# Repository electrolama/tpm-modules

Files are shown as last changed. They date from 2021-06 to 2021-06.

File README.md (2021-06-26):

# tpm-modules

KiCAD (v5.99) designs for Infineon SLB9665 and SLB9670 based TPM modules.

There are two interfaces: SPI (SLB9670) and LPC (SLB9665). Pinouts for the modules vary a lot ([manufacturer specific?](https://superuser.com/a/1537838)) but given how simple the boards are adding new ones should be fairly straightforward. 

Modules in this repo:

**tpm-module-12pin-spi**

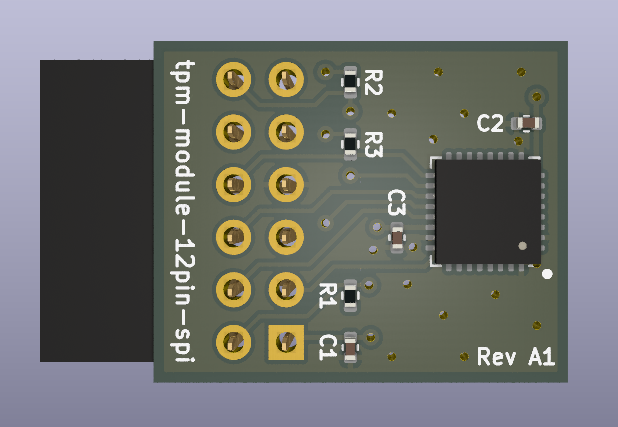
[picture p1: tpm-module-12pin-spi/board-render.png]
tpm-module-12pin-spi


`Status:` Untested, parts ordered for prototypes

**tpm-module-14pin-lpc**

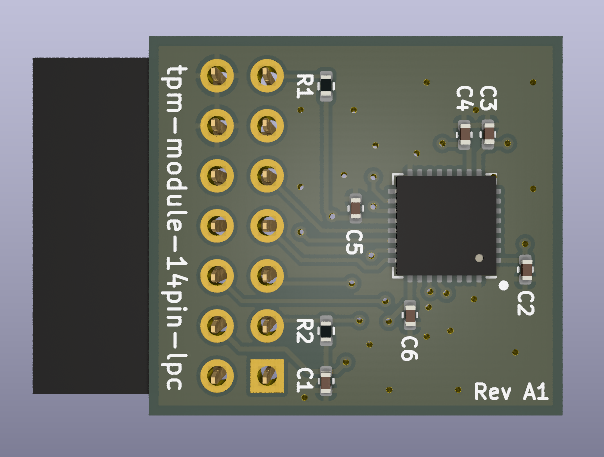
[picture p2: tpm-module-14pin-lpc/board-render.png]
tpm-module-14pin-lpc


`Status:` Untested, please raise a PR if you build and test one.

If you do end up designing a new module, raise a PR so we can collect them all in one repo.

**UNTESTED DESIGNS - COMES WITH NO WARRANTIES OR PROMISES**

THIS MIGHT KILL YOUR COMPUTER AND SET YOUR HOUSE ON FIRE.

YOU HAVE BEEN WARNED.

**License:** CC0 "No Rights Reserved"

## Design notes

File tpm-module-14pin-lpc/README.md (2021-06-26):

Chip: [Infineon Optiga SLB 9665 TPM2.0](https://www.infineon.com/cms/en/product/security-smart-card-solutions/optiga-embedded-security-solutions/optiga-tpm/slb-9665tt2.0/)

Order codes:

SLB9665VQ20FW563XUMA3 (standard temp. range)
SLB9665XQ20FW563XUMA2 (extended temp. range)

Both options work. Package: PG-VQFN-32-13

Chip supply 3.3V, do not use with a 5V header (if that exists?)

Pinout taken from

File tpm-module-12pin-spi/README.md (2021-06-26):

Chip: [Infineon Optiga SLB 9670 TPM2.0](https://www.infineon.com/cms/en/product/security-smart-card-solutions/optiga-embedded-security-solutions/optiga-tpm/slb-9670vq2.0/)

Order codes:
SLB9670VQ20FW785XTMA1 (standard temp. range)
SLB9670XQ20FW785XUMA1 (extended temp. range)

Both options work. Package: PG-VQFN-32-13

Chip supply 1.8V or 3.3V, do not use with a 5V header (if that exists?)

Pinout taken from the user manual for MSI MAG B550M MORTAR WIFI/ MAG B550M MORTAR motherboard ([M7C94v1.2-EURO-1.pdf](https://www.msi.com/Motherboard/support/MAG-B550M-MORTAR#down-manual)).

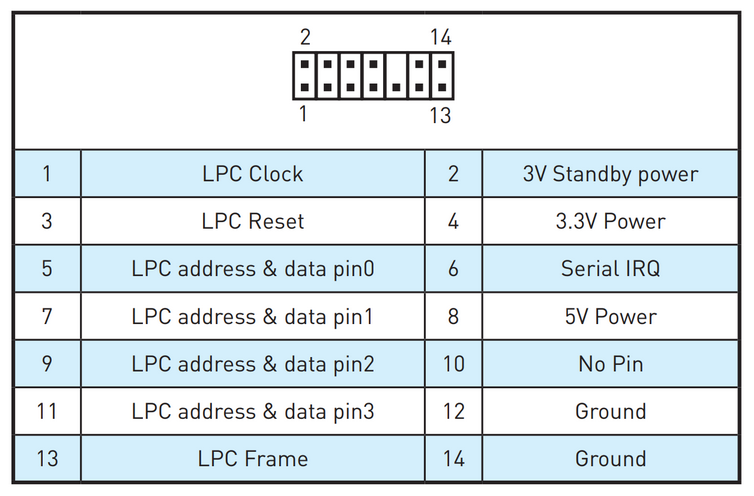
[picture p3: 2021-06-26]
tpm-module-14pin-lpc/14pin-lpc-pinout.png

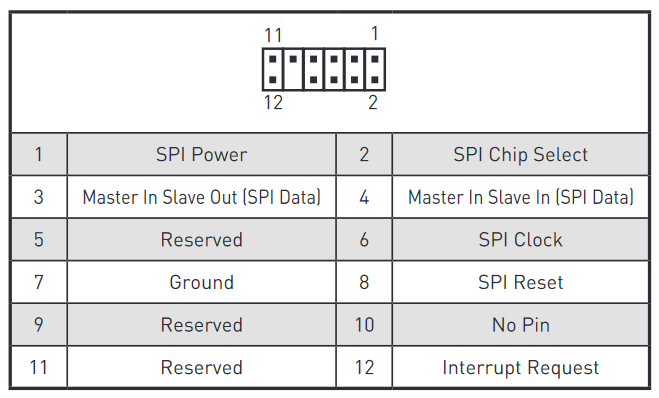
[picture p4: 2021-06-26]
tpm-module-12pin-spi/12pin-spi-pinout.png

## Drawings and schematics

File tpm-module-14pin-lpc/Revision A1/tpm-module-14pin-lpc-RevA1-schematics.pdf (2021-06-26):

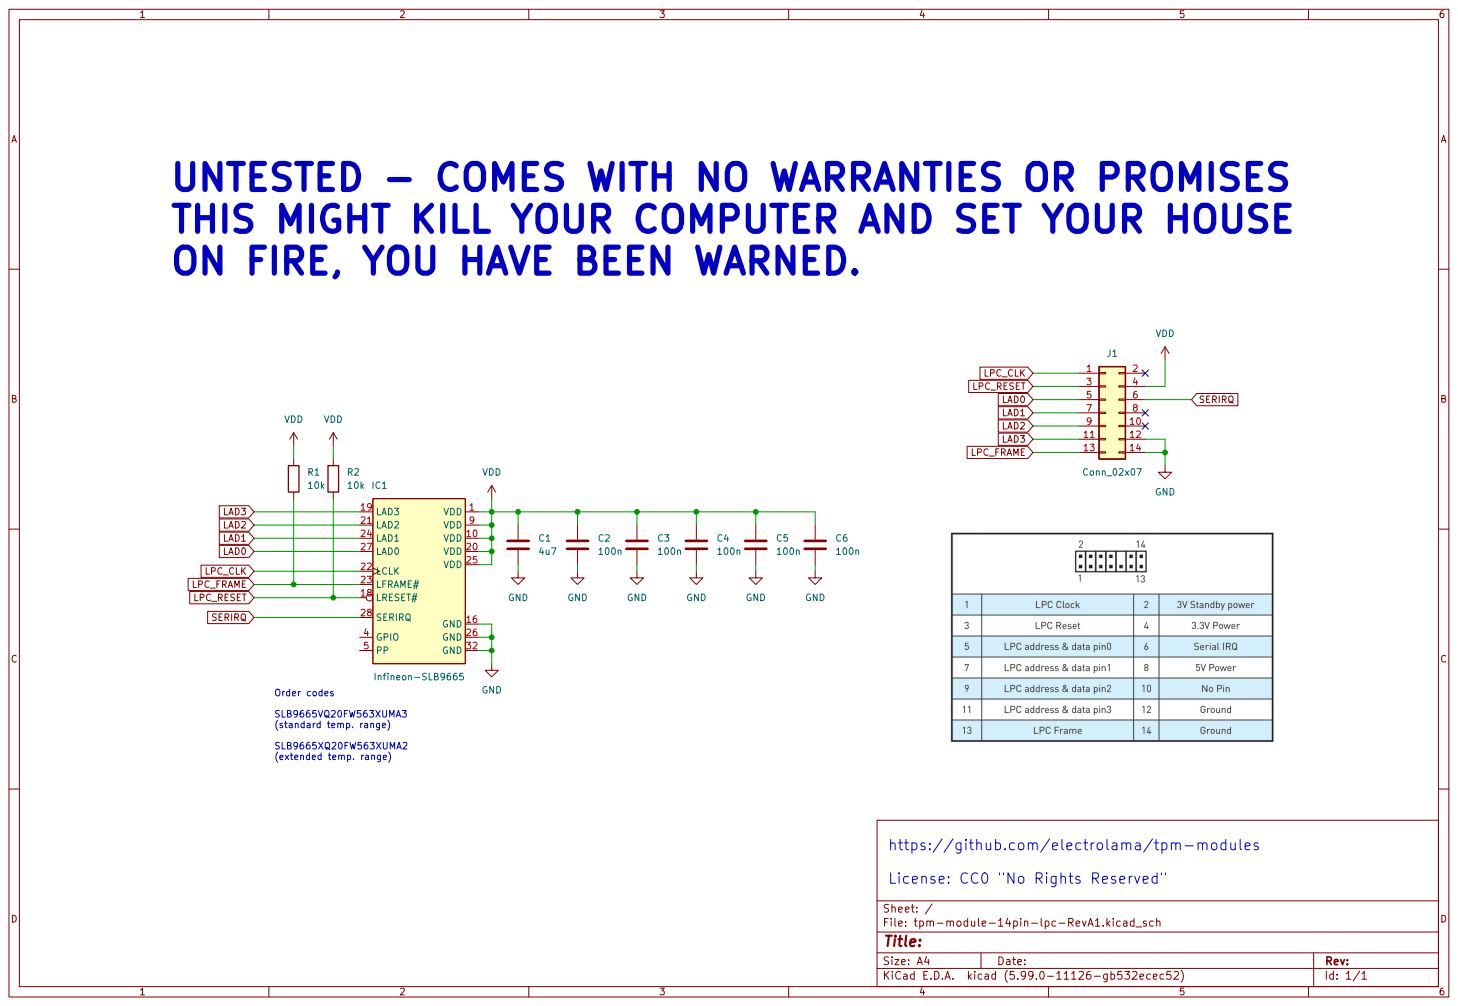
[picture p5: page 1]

LPC_RESET UNTESTED - COMES WITH NO WARRANTIES OR PROMISES
THIS MIGHT KILL YOUR COMPUTER AND SET YOUR HOUSE
ON FIRE, YOU HAVE BEEN WARNED.
Infineon-SLB9665 VDD

File: tpm-module-14pin-lpc-RevA1.kicad_sch Sheet: / C5

LCLK 22
LFRAME# 23

https://github.com/electrolama/tpm-modules

License: CC0 "No Rights Reserved"

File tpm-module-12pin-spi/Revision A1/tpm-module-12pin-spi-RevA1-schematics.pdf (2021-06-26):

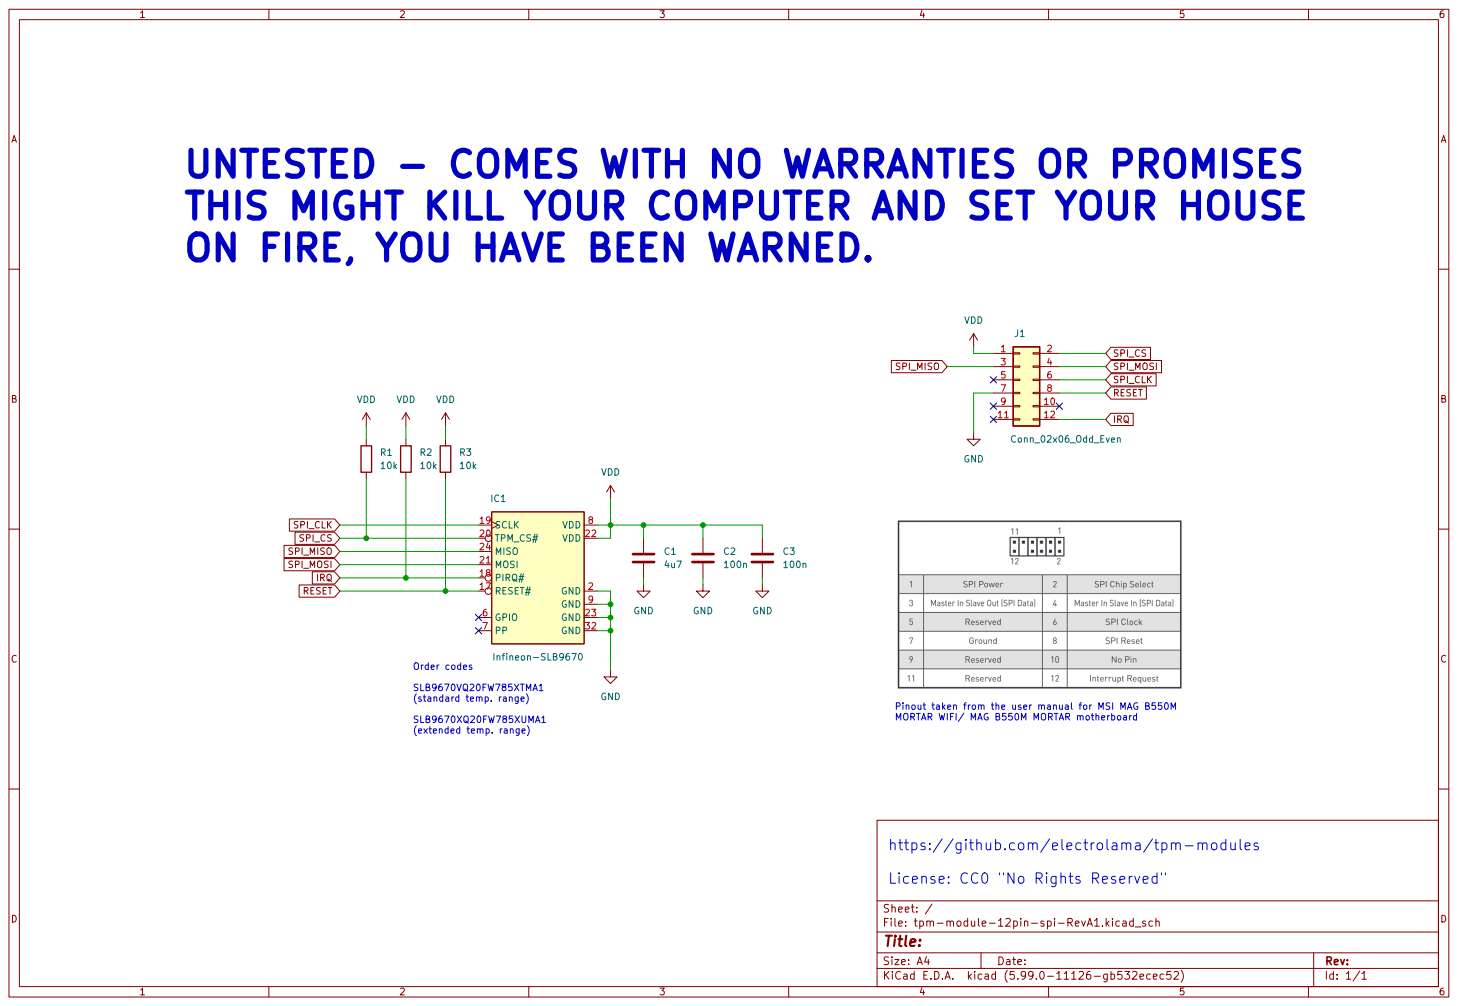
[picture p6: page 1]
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

File: tpm-module-12pin-spi-RevA1.kicad_sch Sheet: / R1

License: CC0 "No Rights Reserved"

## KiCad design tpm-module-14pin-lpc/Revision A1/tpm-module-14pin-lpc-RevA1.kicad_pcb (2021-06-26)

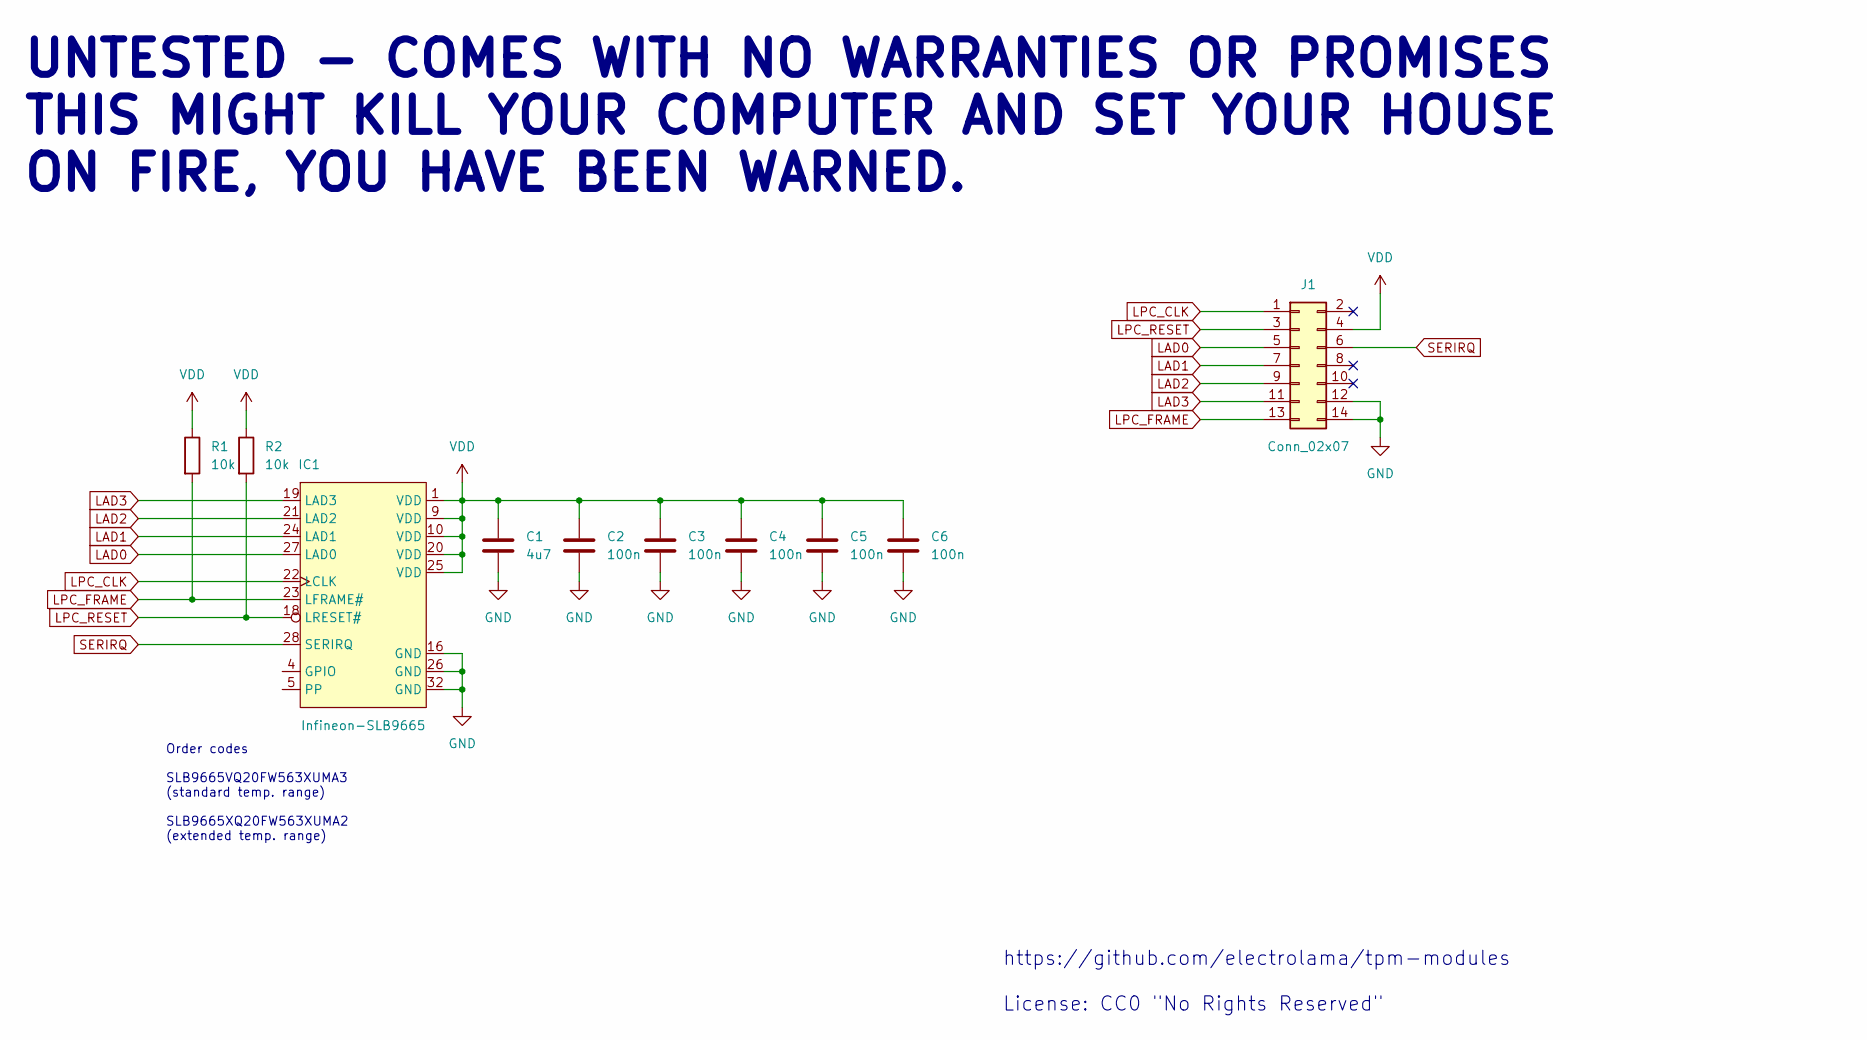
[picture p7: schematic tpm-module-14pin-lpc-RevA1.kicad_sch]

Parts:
C1: 4u7; C_0402_1005Metric
C2, C3, C4, C5, C6: 100n; C_0402_1005Metric
IC1: Infineon-SLB9665; QFN-32-1EP_5x5mm_P0.5mm_EP3.1x3.1mm
J1: Conn_02x07; PinSocket_2x07_P2.54mm_Horizontal
R1, R2: 10k; R_0402_1005Metric

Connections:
GND: C1.2, C2.2, C3.2, C4.2, C5.2, C6.2, IC1.16 (GND), IC1.26 (GND), IC1.32 (GND), J1.12, J1.14
LAD0: IC1.27 (LAD0), J1.5
LAD1: IC1.24 (LAD1), J1.7
LAD2: IC1.21 (LAD2), J1.9
LAD3: IC1.19 (LAD3), J1.11
LPC_CLK: IC1.22 (LCLK), J1.1
LPC_FRAME: IC1.23 (LFRAME#), J1.13, R1.2
LPC_RESET: IC1.18 (LRESET#), J1.3, R2.2
SERIRQ: IC1.28 (SERIRQ), J1.6
VDD: C1.1, C2.1, C3.1, C4.1, C5.1, C6.1, IC1.1 (VDD), IC1.9 (VDD), IC1.10 (VDD), IC1.20 (VDD), IC1.25 (VDD), J1.4, R1.1, R2.1

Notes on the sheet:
UNTESTED - COMES WITH NO WARRANTIES OR PROMISES THIS MIGHT KILL YOUR COMPUTER AND SET YOUR HOUSE ON FIRE, YOU HAVE BEEN WARNED.
Order codes SLB9665VQ20FW563XUMA3 (standard temp. range) SLB9665XQ20FW563XUMA2 (extended temp. range)
https://github.com/electrolama/tpm-modules License: CC0 "No Rights Reserved"

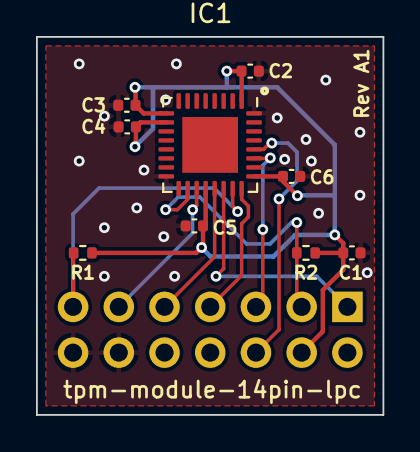
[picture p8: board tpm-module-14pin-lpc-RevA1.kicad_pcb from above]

Board: 2 copper layers, 19.2 x 21.0 mm, 10 parts (1 on the bottom side), 10 nets.

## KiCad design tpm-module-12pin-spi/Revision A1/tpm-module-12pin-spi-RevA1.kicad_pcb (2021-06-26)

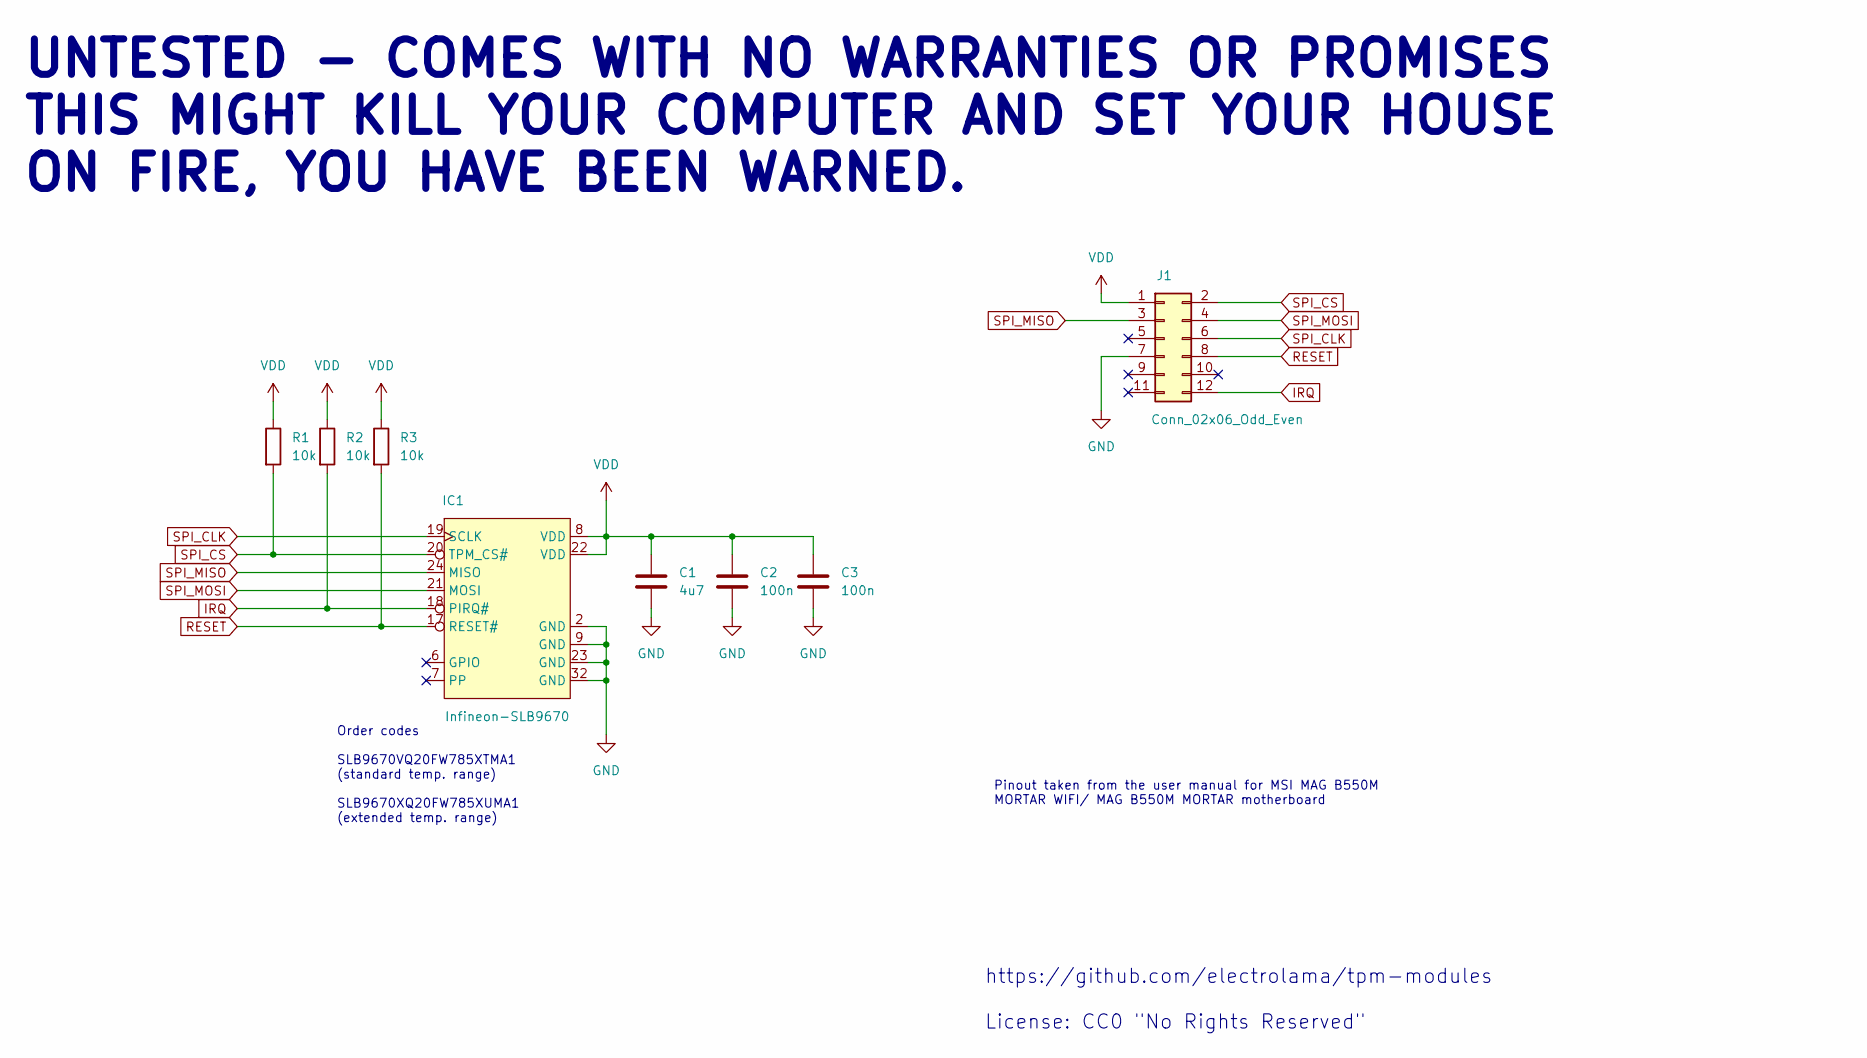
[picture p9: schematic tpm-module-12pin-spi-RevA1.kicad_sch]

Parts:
C1: 4u7; C_0402_1005Metric
C2, C3: 100n; C_0402_1005Metric
IC1: Infineon-SLB9670; QFN-32-1EP_5x5mm_P0.5mm_EP3.1x3.1mm
J1: Conn_02x06_Odd_Even; PinSocket_2x06_P2.54mm_Horizontal
R1, R2, R3: 10k; R_0402_1005Metric

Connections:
GND: C1.2, C2.2, C3.2, IC1.2 (GND), IC1.9 (GND), IC1.23 (GND), IC1.32 (GND), J1.7
IRQ: IC1.18 (PIRQ#), J1.12, R2.2
RESET: IC1.17 (RESET#), J1.8, R3.2
SPI_CLK: IC1.19 (SCLK), J1.6
SPI_CS: IC1.20 (TPM_CS#), J1.2, R1.2
SPI_MISO: IC1.24 (MISO), J1.3
SPI_MOSI: IC1.21 (MOSI), J1.4
VDD: C1.1, C2.1, C3.1, IC1.8 (VDD), IC1.22 (VDD), J1.1, R1.1, R2.1, R3.1

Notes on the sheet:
UNTESTED - COMES WITH NO WARRANTIES OR PROMISES THIS MIGHT KILL YOUR COMPUTER AND SET YOUR HOUSE ON FIRE, YOU HAVE BEEN WARNED.
Order codes SLB9670VQ20FW785XTMA1 (standard temp. range) SLB9670XQ20FW785XUMA1 (extended temp. range)
https://github.com/electrolama/tpm-modules License: CC0 "No Rights Reserved"
Pinout taken from the user manual for MSI MAG B550M MORTAR WIFI/ MAG B550M MORTAR motherboard

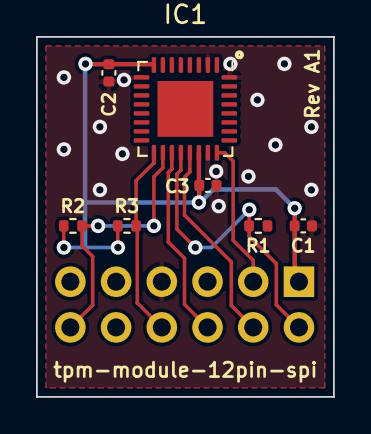
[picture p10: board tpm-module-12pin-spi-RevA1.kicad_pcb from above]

Board: 2 copper layers, 16.5 x 20.0 mm, 8 parts (1 on the bottom side), 8 nets.

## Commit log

2021-06-26 add kicad symbols for SLB9665 and SLB9670
2021-06-26 initial commit for tpm-module-12pin-spi-RevA1
    [tpm-module-12pin-spi-RevA1.kicad_pcb, tpm-module-12pin-spi-RevA1.kicad_sch]
2021-06-26 initial commit for tpm-module-14pin-lpc-RevA1
    [tpm-module-14pin-lpc-RevA1.kicad_pcb, tpm-module-14pin-lpc-RevA1.kicad_sch]
